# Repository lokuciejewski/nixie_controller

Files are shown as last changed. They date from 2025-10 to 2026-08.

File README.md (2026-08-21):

# Controller/clock for mini Nixie I2C modules

STM32-based controller board that uses 4 [nixie modules](https://github.com/lokuciejewski/nixie_module) to display the current time. The modules can be changed at any time the board is off and swapped if the nixie tube goes bad or the user wants to insert a different nixie tube.

V1 board with 4 modules

The board uses a STM32U031 microcontroller coupled with DS3231 RTC to achieve low power, reliable timekeeping.
For High Voltage for the nixie tubes, it uses a premade nixie PSU 160-180V (available on aliexpress). It uses a single cell CR2032 battery to keep the time when the module is not connected. For communication, it uses a serial interface over the USB-C port (which also serves as the power input). The board features 3 programmable buttons and two LEDs for signalling the system status.

V1 empty board
Note: V1 version of the board contains multiple test points and additional inputs which will be removed in the V2 version.

## Building

Prerequisites:

- Rust
- `cargo`

To build, simply run `cargo build --release`

## Flashing

The board is flashed using `probe-rs`, which can utilize a range of multiple programmers, for example an ST-Link.
Connect the programmer to the J3 and run `cargo run --release`.

## Operation

Currently, the time can only be set using the serial port and the `comm.py` script.

The serial protocol for talking to the board can be found [in the `serial` directory](./src/serial/)

## Planned features

V2 will have an option to wire 1 or 2 neon tubes between the hour and minute displays (since not all nixie tubes come with a comma).

It may also be equipped with the human presence sensor to only light up when it can detect a human.

A console interface is planned to utilize all features of the board (such as programming inputs, time, etc.)

The board has a second serial available on pins which may be used for wireless time access via e.g. an esp32.

V1 board with nixies off

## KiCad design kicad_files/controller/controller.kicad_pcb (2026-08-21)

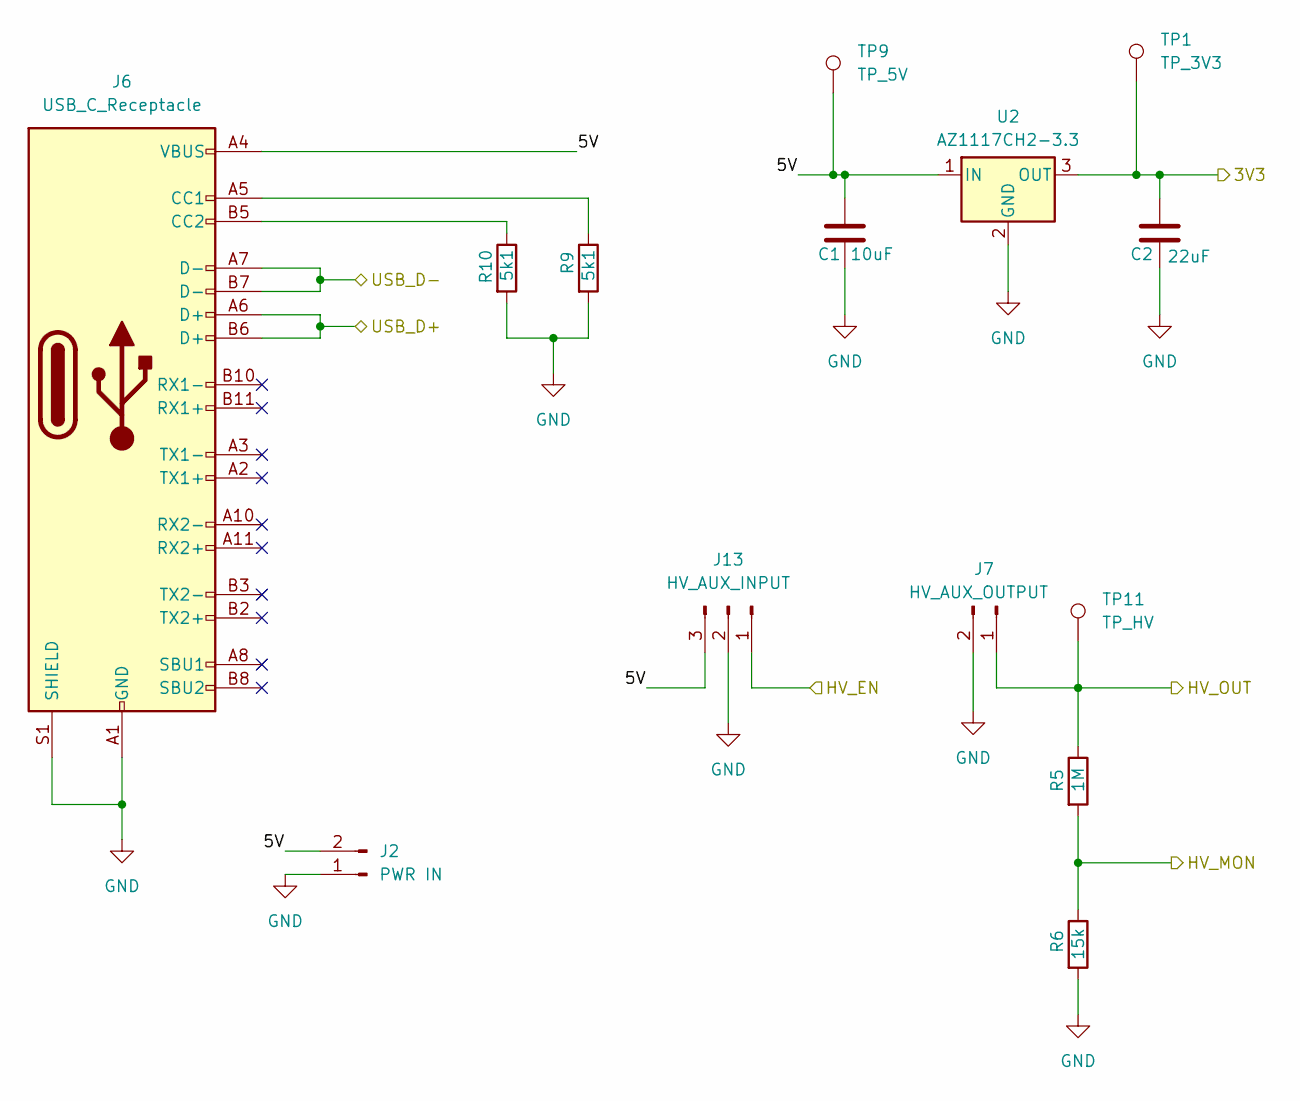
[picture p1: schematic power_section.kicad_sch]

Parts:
C1: 10uF; C_0603_1608Metric_Pad1.08x0.95mm_HandSolder
C2: 22uF; C_0603_1608Metric_Pad1.08x0.95mm_HandSolder
J2: PWR IN; PinHeader_1x02_P2.54mm_Vertical
J6: USB_C_Receptacle; USB_C_Receptacle_GCT_USB4085
J7: HV_AUX_OUTPUT; PinHeader_1x02_P2.54mm_Vertical
J13: HV_AUX_INPUT; PinHeader_1x03_P2.54mm_Vertical
R5: 1M; R_0805_2012Metric_Pad1.20x1.40mm_HandSolder
R6: 15k; R_0603_1608Metric_Pad0.98x0.95mm_HandSolder
R9, R10: 5k1; R_0603_1608Metric_Pad0.98x0.95mm_HandSolder
TP1: TP_3V3; TestPoint_Pad_D1.0mm
TP9: TP_5V; TestPoint_Pad_D1.0mm
TP11: TP_HV; TestPoint_Pad_D1.0mm
U2: AZ1117CH2-3.3; SOT-223-3_TabPin2

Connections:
/MCU/3V3: C2.1, TP1.1, U2.3 (OUT); also elsewhere on the board
/MCU/HV_EN: J13.1; also elsewhere on the board
/MCU/HV_MON: R5.2, R6.1; also elsewhere on the board
/MCU/USB_D+: J6.A6 (D+), J6.B6 (D+); also elsewhere on the board
/MCU/USB_D-: J6.A7 (D-), J6.B7 (D-); also elsewhere on the board
/Nixie Module Mounts/HV0: J7.1, R5.1, TP11.1; also elsewhere on the board
/Power Section/5V: C1.1, J2.2, J6.A4 (VBUS), J6.A9 (VBUS), J6.B4 (VBUS), J6.B9 (VBUS), J13.3, TP9.1, U2.1 (IN)
GND: C1.2, C2.2, J2.1, J6.A1 (GND), J6.A12 (GND), J6.B1 (GND), J6.B12 (GND), J6.S1 (SHIELD), J7.2, J13.2, R6.2, R9.2, R10.2, U2.2 (GND); also elsewhere on the board
unnamed: J6.A5 (CC1), R9.1
unnamed: J6.B5 (CC2), R10.1

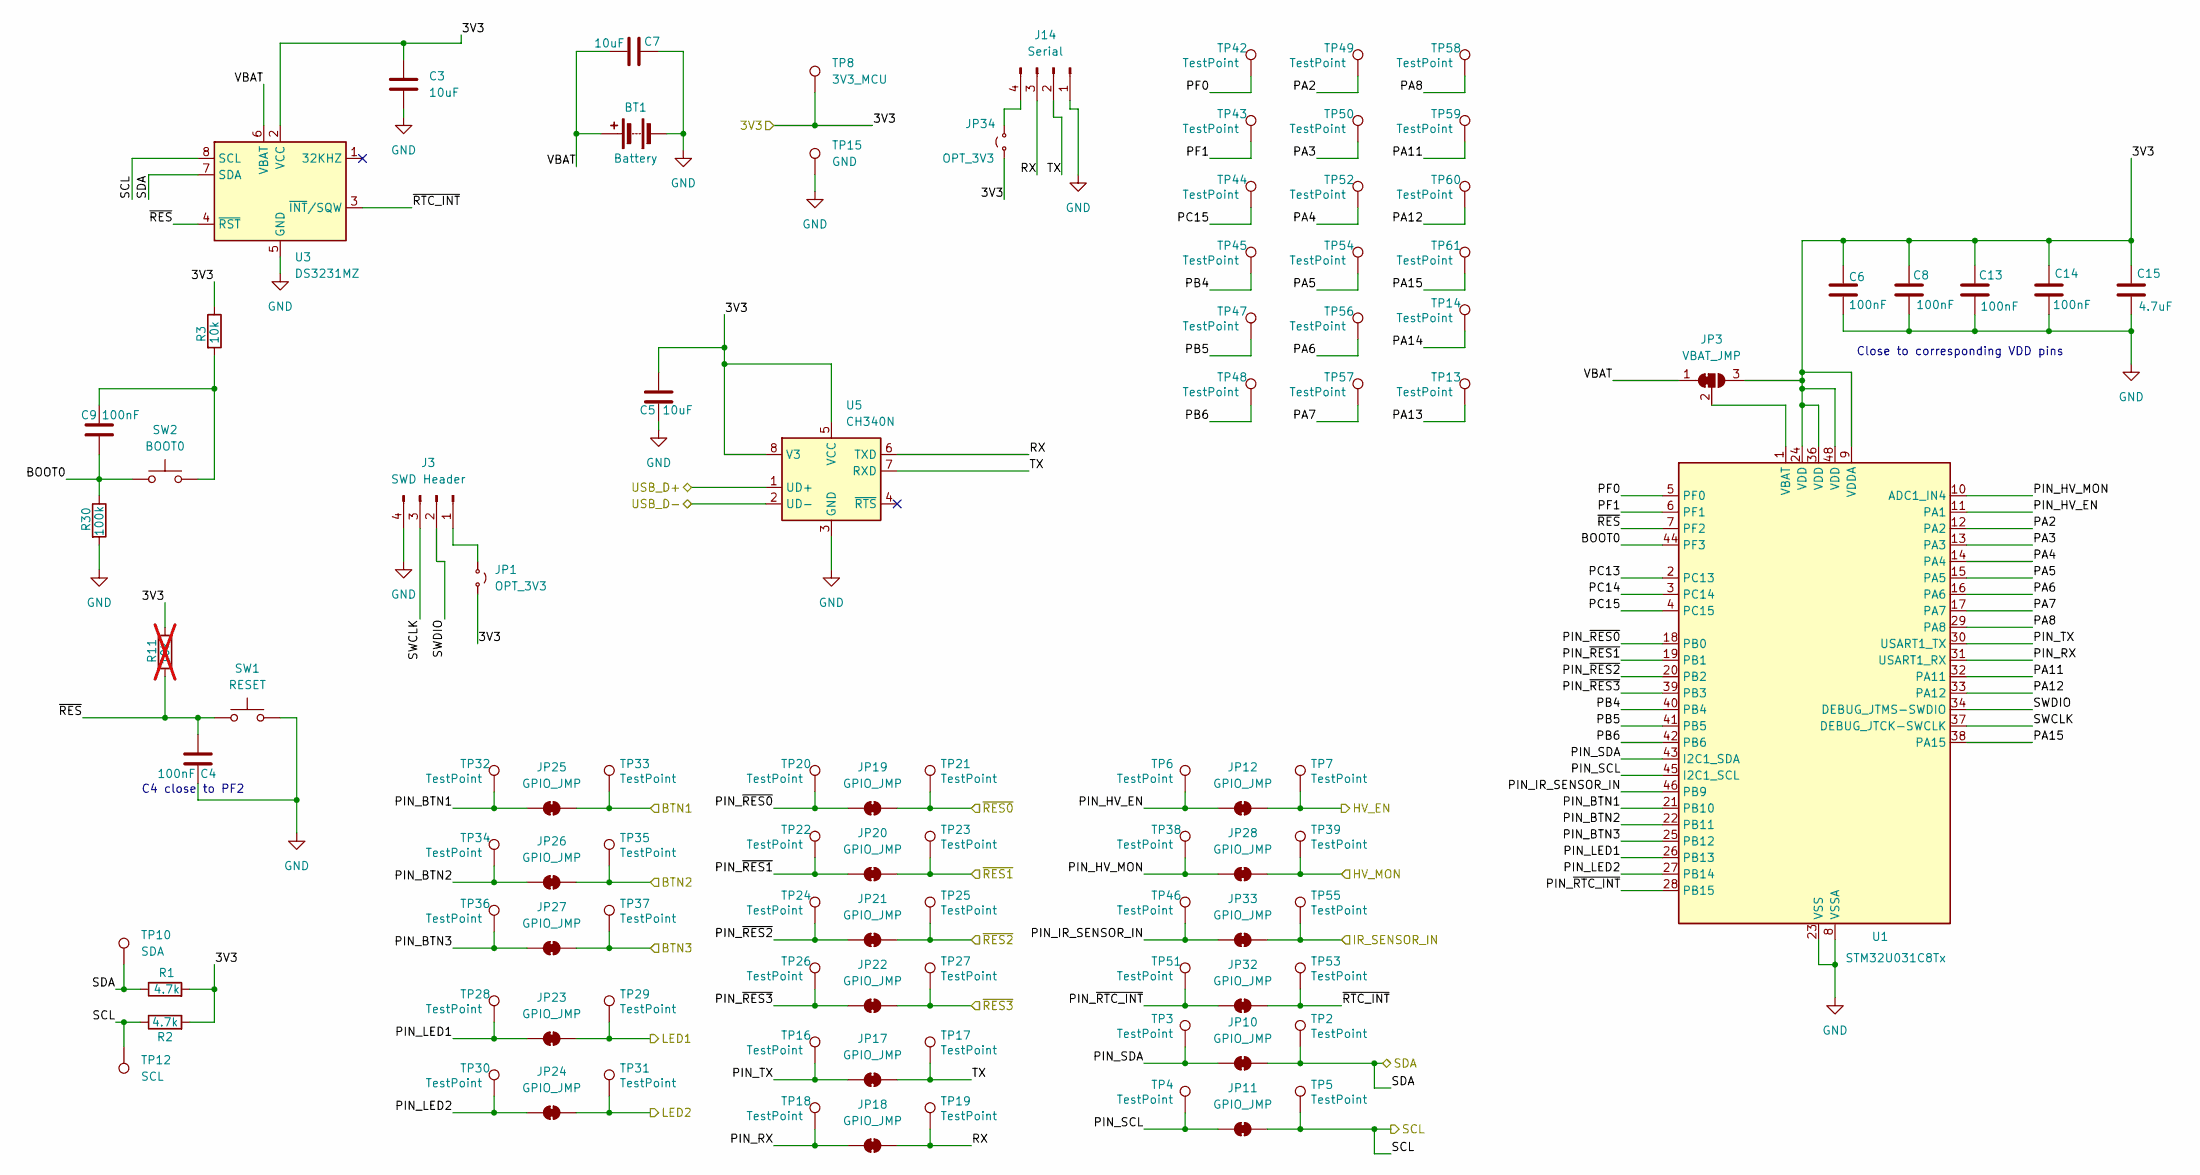
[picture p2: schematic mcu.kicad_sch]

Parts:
BT1: Battery; BatteryHolder_Keystone_1060_1x2032
C3, C5, C7: 10uF; C_0603_1608Metric_Pad1.08x0.95mm_HandSolder
C4, C6, C8, C9, C13, C14: 100nF; C_0603_1608Metric_Pad1.08x0.95mm_HandSolder
C15: 4.7uF; C_0603_1608Metric_Pad1.08x0.95mm_HandSolder
J3: SWD Header; PinHeader_1x04_P2.54mm_Vertical
J14: Serial; PinHeader_1x04_P2.54mm_Vertical
JP1, JP34: OPT_3V3; SolderJumper-2_P1.3mm_Open_RoundedPad1.0x1.5mm
JP3: VBAT_JMP; SolderJumper-3_P1.3mm_Bridged2Bar12_RoundedPad1.0x1.5mm_Num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
JP10, JP11, JP12, JP17, JP18, JP19, JP20, JP21, JP22, JP23, JP24, JP25, JP26, JP27, JP28, JP32, JP33: GPIO_JMP; SolderJumper-2_P1.3mm_Bridged2Bar_RoundedPad1.0x1.5mm
R1, R2: 4.7k; R_0603_1608Metric_Pad0.98x0.95mm_HandSolder
R3: 10k; R_0603_1608Metric_Pad0.98x0.95mm_HandSolder
R11: 10k; R_0603_1608Metric_Pad0.98x0.95mm_HandSolder; not fitted
R30: 100k; R_0603_1608Metric_Pad0.98x0.95mm_HandSolder
SW1: RESET; SW_SPST_TL3305A
SW2: BOOT0; SW_SPST_TL3305A
TP2, TP3, TP4, TP5, TP6, TP7, TP13, TP14, TP16, TP17, TP18, TP19, TP20, TP21, TP22, TP23, TP24, TP25, TP26, TP27, TP28, TP29, TP30, TP31, TP32, TP33, TP34, TP35, TP36, TP37, TP38, TP39, TP42, TP43, TP44, TP45, TP46, TP47, TP48, TP49, TP50, TP51, TP52, TP53, TP54, TP55, TP56, TP57, TP58, TP59, TP60, TP61: TestPoint; TestPoint_Pad_D1.0mm
TP8: 3V3_MCU; TestPoint_Pad_D1.0mm
TP10: SDA; TestPoint_Pad_D1.0mm
TP12: SCL; TestPoint_Pad_D1.0mm
TP15: GND; TestPoint_Pad_D1.0mm
U1: STM32U031C8Tx; LQFP-48_7x7mm_P0.5mm
U3: DS3231MZ; SOIC-8_3.9x4.9mm_P1.27mm
U5: CH340N; JEITA_SOIC-8_3.9x4.9mm_P1.27mm

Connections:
/IO Section/BTN_1: JP25.2 (B), TP33.1; also elsewhere on the board
/IO Section/BTN_2: JP26.2 (B), TP35.1; also elsewhere on the board
/IO Section/BTN_3: JP27.2 (B), TP37.1; also elsewhere on the board
/IO Section/IR_SENSOR_OUT: JP33.2 (B), TP55.1; also elsewhere on the board
/IO Section/LED_1: JP23.2 (B), TP29.1; also elsewhere on the board
/IO Section/LED_2: JP24.2 (B), TP31.1; also elsewhere on the board
/MCU/3V3: C3.1, C5.1, C6.1, C8.1, C13.1, C14.1, C15.1, JP1.2 (B), JP3.3 (B), JP34.1 (A), R1.2, R2.2, R3.1, R11.1, TP8.1, U1.9 (VDDA), U1.24 (VDD), U1.36 (VDD), U1.48 (VDD), U3.2 (VCC), U5.5 (VCC), U5.8 (V3); also elsewhere on the board
/MCU/BOOT0: C9.1, R30.1, SW2.1, U1.44 (PF3)
/MCU/HV_EN: JP12.2 (B), TP7.1; also elsewhere on the board
/MCU/HV_MON: JP28.2 (B), TP39.1; also elsewhere on the board
/MCU/PA2: TP49.1, U1.12 (PA2)
/MCU/PA3: TP50.1, U1.13 (PA3)
/MCU/PA4: TP52.1, U1.14 (PA4)
/MCU/PA5: TP54.1, U1.15 (PA5)
/MCU/PA6: TP56.1, U1.16 (PA6)
/MCU/PA7: TP57.1, U1.17 (PA7)
/MCU/PA8: TP58.1, U1.29 (PA8)
/MCU/PA11: TP59.1, U1.32 (PA11)
/MCU/PA12: TP60.1, U1.33 (PA12)
/MCU/PA13: TP13.1
/MCU/PA14: TP14.1
/MCU/PA15: TP61.1, U1.38 (PA15)
/MCU/PB4: TP45.1, U1.40 (PB4)
/MCU/PB5: TP47.1, U1.41 (PB5)
/MCU/PB6: TP48.1, U1.42 (PB6)
/MCU/PC13: U1.2 (PC13)
/MCU/PC14: U1.3 (PC14)
/MCU/PC15: TP44.1, U1.4 (PC15)
/MCU/PF0: TP42.1, U1.5 (PF0)
/MCU/PF1: TP43.1, U1.6 (PF1)
/MCU/PIN_BTN1: JP25.1 (A), TP32.1, U1.21 (PB10)
/MCU/PIN_BTN2: JP26.1 (A), TP34.1, U1.22 (PB11)
/MCU/PIN_BTN3: JP27.1 (A), TP36.1, U1.25 (PB12)
/MCU/PIN_HV_EN: JP12.1 (A), TP6.1, U1.11 (PA1)
/MCU/PIN_HV_MON: JP28.1 (A), TP38.1, U1.10 (ADC1_IN4)
/MCU/PIN_IR_SENSOR_IN: JP33.1 (A), TP46.1, U1.46 (PB9)
/MCU/PIN_LED1: JP23.1 (A), TP28.1, U1.26 (PB13)
/MCU/PIN_LED2: JP24.1 (A), TP30.1, U1.27 (PB14)
/MCU/PIN_RX: JP18.1 (A), TP18.1, U1.31 (USART1_RX)
/MCU/PIN_SCL: JP11.1 (A), TP4.1, U1.45 (I2C1_SCL)
/MCU/PIN_SDA: JP10.1 (A), TP3.1, U1.43 (I2C1_SDA)
/MCU/PIN_TX: JP17.1 (A), TP16.1, U1.30 (USART1_TX)
/MCU/PIN_~RES0: JP19.1 (A), TP20.1, U1.18 (PB0)
/MCU/PIN_~RES1: JP20.1 (A), TP22.1, U1.19 (PB1)
/MCU/PIN_~RES2: JP21.1 (A), TP24.1, U1.20 (PB2)
/MCU/PIN_~RES3: JP22.1 (A), TP26.1, U1.39 (PB3)
/MCU/PIN_~RTC_INT: JP32.1 (A), TP51.1, U1.28 (PB15)
/MCU/RX: J14.3, JP18.2 (B), TP19.1, U5.6 (TXD)
/MCU/SCL: JP11.2 (B), R2.1, TP5.1, TP12.1, U3.8 (SCL); also elsewhere on the board
/MCU/SDA: JP10.2 (B), R1.1, TP2.1, TP10.1, U3.7 (SDA); also elsewhere on the board
/MCU/SWCLK: J3.3, U1.37 (DEBUG_JTCK-SWCLK)
/MCU/SWDIO: J3.2, U1.34 (DEBUG_JTMS-SWDIO)
/MCU/TX: J14.2, JP17.2 (B), TP17.1, U5.7 (RXD)
/MCU/USB_D+: U5.1 (UD+); also elsewhere on the board
/MCU/USB_D-: U5.2 (UD-); also elsewhere on the board
/MCU/VBAT: BT1.1 (+), C7.2, JP3.1 (A), U3.6 (VBAT)
/MCU/~RES0: JP19.2 (B), TP21.1; also elsewhere on the board
/MCU/~RES1: JP20.2 (B), TP23.1; also elsewhere on the board
/MCU/~RES2: JP21.2 (B), TP25.1; also elsewhere on the board
/MCU/~RES3: JP22.2 (B), TP27.1; also elsewhere on the board
/MCU/~RES: C4.1, R11.2, SW1.1, U1.7 (PF2), U3.4 (~RST)
/MCU/~RTC_INT: JP32.2 (B), TP53.1, U3.3 (~INT/SQW)
GND: BT1.2 (-), C3.2, C4.2, C5.2, C6.2, C7.1, C8.2, C13.2, C14.2, C15.2, J3.4, J14.1, R30.2, SW1.2, TP15.1, U1.8 (VSSA), U1.23 (VSS), U3.5 (GND), U5.3 (GND); also elsewhere on the board
unnamed: C9.2, R3.2, SW2.2
unnamed: J3.1, JP1.1 (A)
unnamed: J14.4, JP34.2 (B)
unnamed: JP3.2 (C), U1.1 (VBAT)
unnamed: U1.35 (VSS), U1.47 (VSS)

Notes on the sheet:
Close to corresponding VDD pins
C4 close to PF2

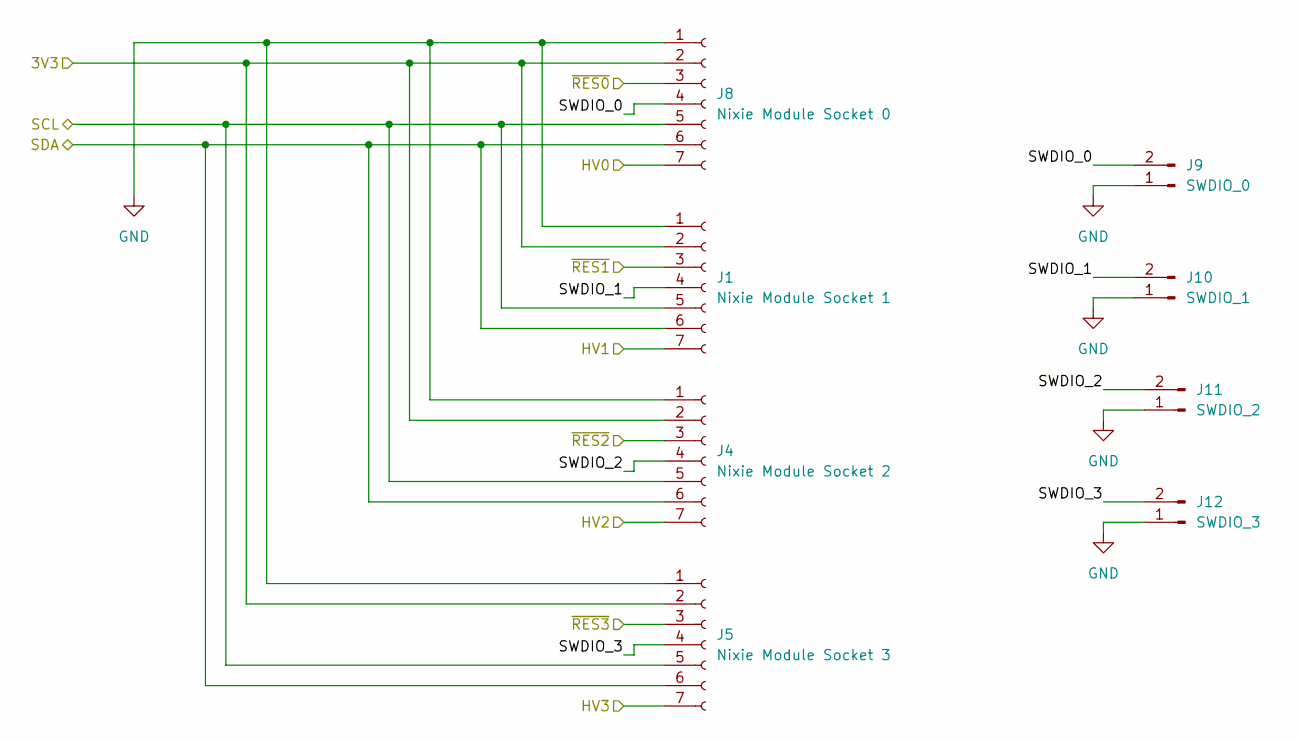
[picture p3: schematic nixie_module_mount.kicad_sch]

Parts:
J1: Nixie Module Socket 1; PinHeader_1x07_P2.54mm_Vertical
J4: Nixie Module Socket 2; PinHeader_1x07_P2.54mm_Vertical
J5: Nixie Module Socket 3; PinHeader_1x07_P2.54mm_Vertical
J8: Nixie Module Socket 0; PinHeader_1x07_P2.54mm_Vertical
J9: SWDIO_0; PinHeader_1x02_P2.54mm_Vertical
J10: SWDIO_1; PinHeader_1x02_P2.54mm_Vertical
J11: SWDIO_2; PinHeader_1x02_P2.54mm_Vertical
J12: SWDIO_3; PinHeader_1x02_P2.54mm_Vertical

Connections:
/MCU/3V3: J1.2, J4.2, J5.2, J8.2; also elsewhere on the board
/MCU/SCL: J1.5, J4.5, J5.5, J8.5; also elsewhere on the board
/MCU/SDA: J1.6, J4.6, J5.6, J8.6; also elsewhere on the board
/MCU/~RES0: J8.3; also elsewhere on the board
/MCU/~RES1: J1.3; also elsewhere on the board
/MCU/~RES2: J4.3; also elsewhere on the board
/MCU/~RES3: J5.3; also elsewhere on the board
/Nixie Module Mounts/HV0: J1.7, J4.7, J5.7, J8.7; also elsewhere on the board
/Nixie Module Mounts/SWDIO_0: J8.4, J9.2
/Nixie Module Mounts/SWDIO_1: J1.4, J10.2
/Nixie Module Mounts/SWDIO_2: J4.4, J11.2
/Nixie Module Mounts/SWDIO_3: J5.4, J12.2
GND: J1.1, J4.1, J5.1, J8.1, J9.1, J10.1, J11.1, J12.1; also elsewhere on the board

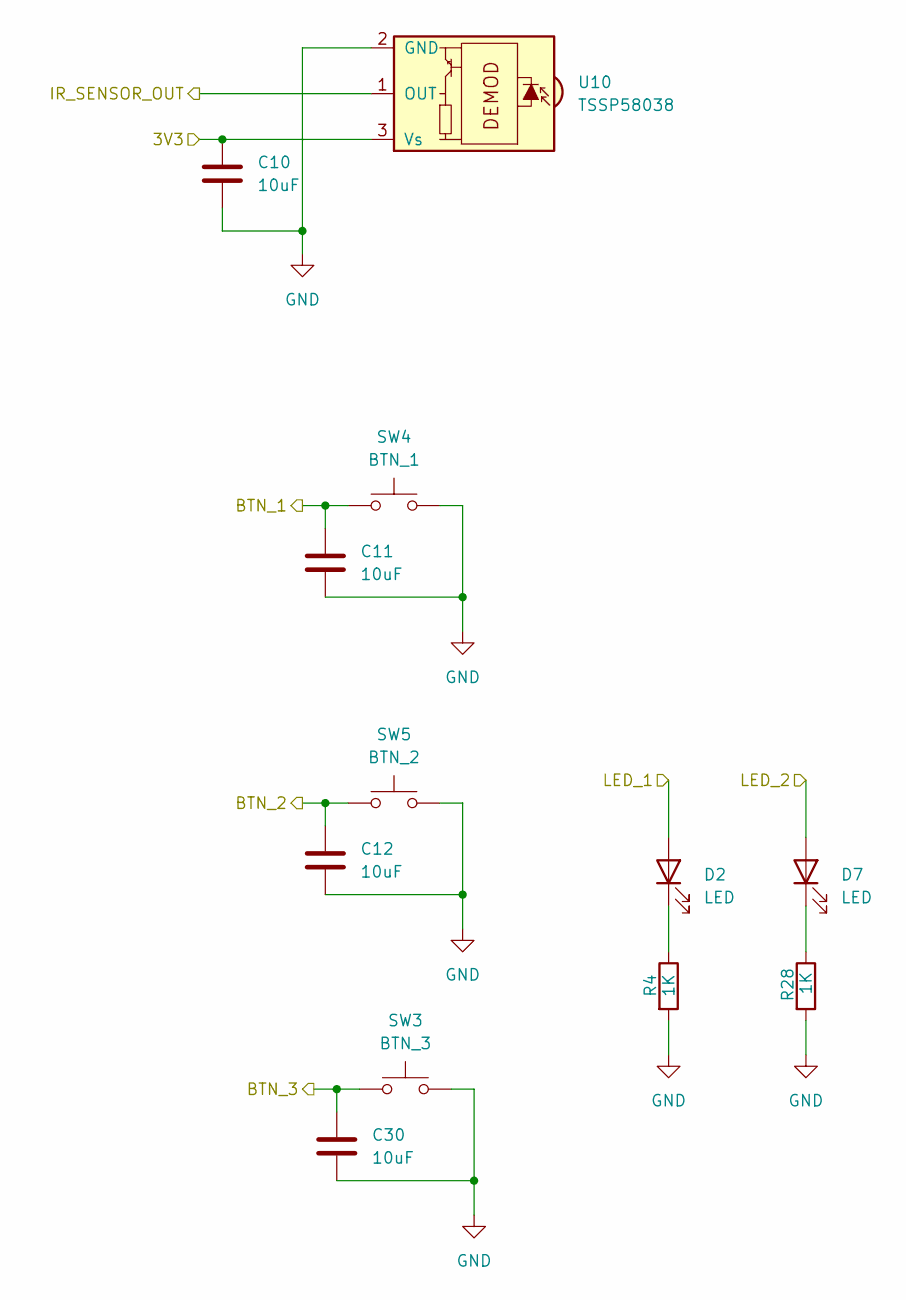
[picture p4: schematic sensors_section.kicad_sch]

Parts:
C10, C11, C12, C30: 10uF; C_0603_1608Metric_Pad1.08x0.95mm_HandSolder
D2, D7: LED; LED_0603_1608Metric_Pad1.05x0.95mm_HandSolder
R4, R28: 1K; R_0603_1608Metric_Pad0.98x0.95mm_HandSolder
SW3: BTN_3; SW_Tactile_SPST_Angled_PTS645Vx39-2LFS
SW4: BTN_1; SW_Tactile_SPST_Angled_PTS645Vx39-2LFS
SW5: BTN_2; SW_Tactile_SPST_Angled_PTS645Vx39-2LFS
U10: TSSP58038; Vishay_MINICAST-3Pin

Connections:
/IO Section/BTN_1: C11.1, SW4.1; also elsewhere on the board
/IO Section/BTN_2: C12.1, SW5.1; also elsewhere on the board
/IO Section/BTN_3: C30.1, SW3.1; also elsewhere on the board
/IO Section/IR_SENSOR_OUT: U10.1 (OUT); also elsewhere on the board
/IO Section/LED_1: D2.2 (A); also elsewhere on the board
/IO Section/LED_2: D7.2 (A); also elsewhere on the board
/MCU/3V3: C10.1, U10.3 (Vs); also elsewhere on the board
GND: C10.2, C11.2, C12.2, C30.2, R4.2, R28.2, SW3.2, SW4.2, SW5.2, U10.2 (GND); also elsewhere on the board
unnamed: D2.1 (K), R4.1
unnamed: D7.1 (K), R28.1

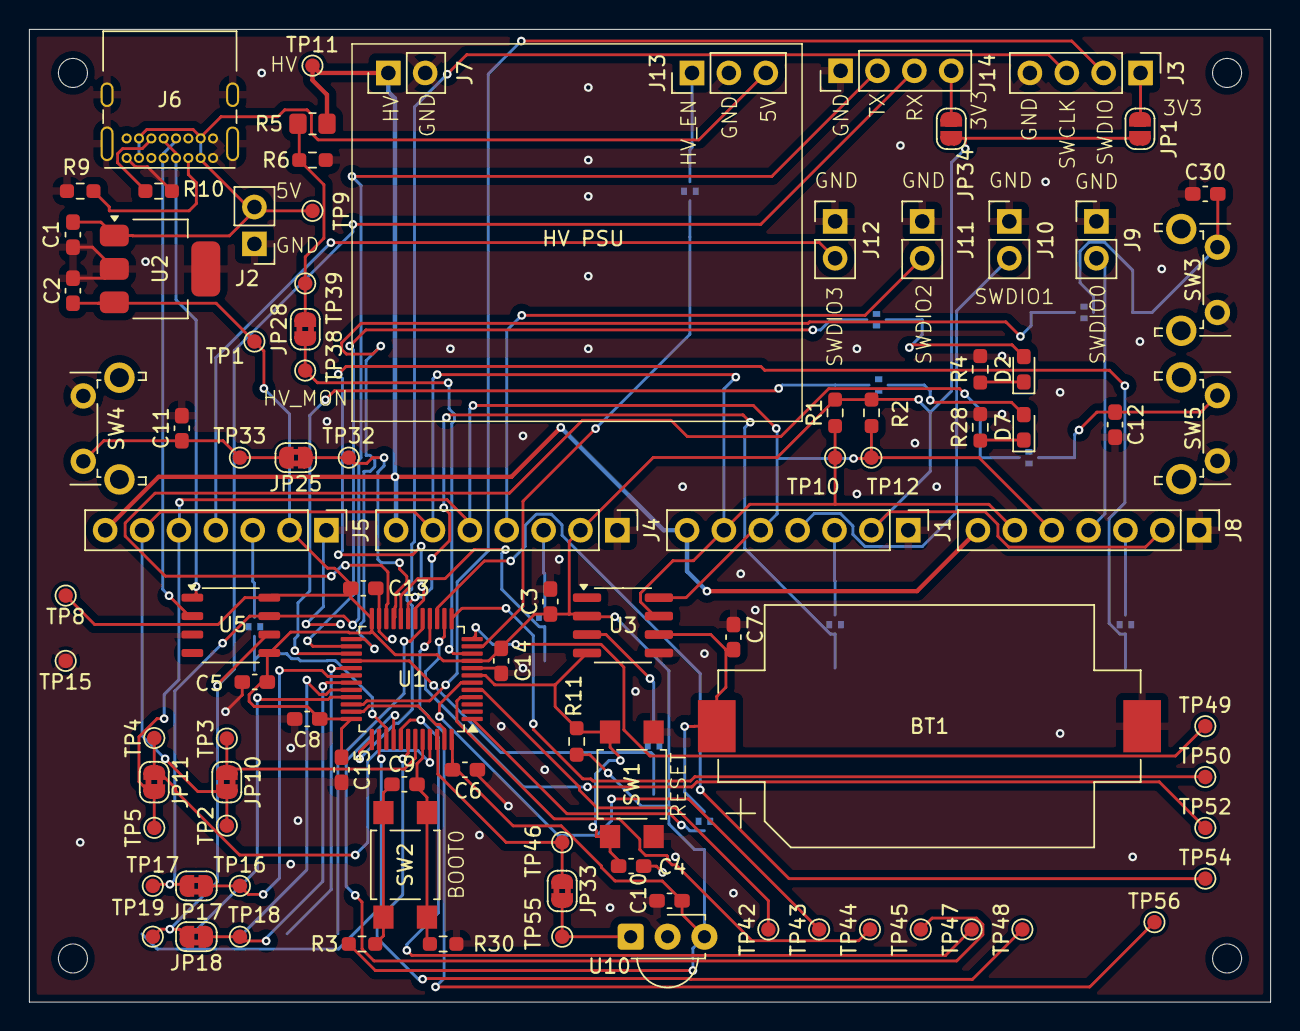
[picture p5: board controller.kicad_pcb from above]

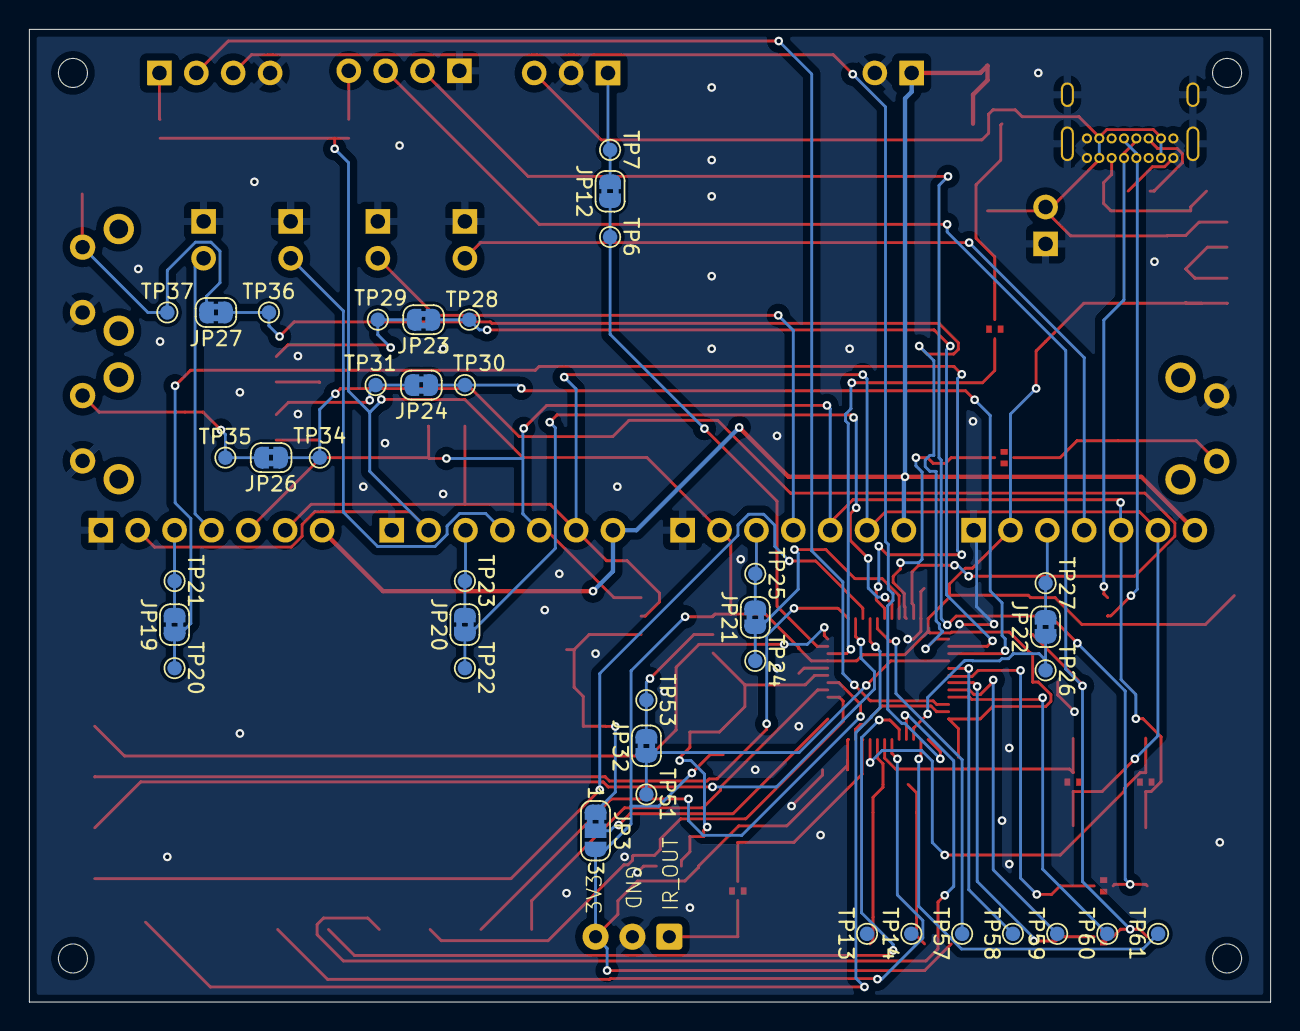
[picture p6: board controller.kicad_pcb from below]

Board: 2 copper layers, 85.5 x 67.0 mm, 133 parts (38 on the bottom side), 74 nets.

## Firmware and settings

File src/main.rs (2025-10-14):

#![no_std]
#![no_main]

mod board_config;
mod buttons;
mod ir_sensor;
mod leds;
mod nixie_controller;
mod rtc;
mod serial;

use chrono::{NaiveDateTime, Timelike};
use embassy_stm32::peripherals::USART1;
use embassy_sync::blocking_mutex::raw::{CriticalSectionRawMutex, NoopRawMutex};
use embassy_sync::mutex::Mutex;
use embassy_sync::signal::Signal;
use embassy_sync::watch::Watch;
use static_cell::StaticCell;

use crate::board_config::*;
use crate::buttons::button_task;
use crate::ir_sensor::ir_sensor_task;
use crate::leds::{led_task, SystemState};
use crate::nixie_controller::nixie_controller_task;
use crate::rtc::rtc_task;
use crate::serial::protocol::ProgramMode;
use crate::serial::serial::serial_task;
use cortex_m_rt::{exception, ExceptionFrame};
use defmt::*;
use defmt_rtt as _;
use embassy_executor::Spawner;
use embassy_stm32::{bind_interrupts, i2c::I2c, peripherals::I2C1};
use embassy_time::{Duration, Ticker};
use panic_probe as _;

use defmt::panic;

type I2cBus =
    Mutex<NoopRawMutex, I2c<'static, embassy_stm32::mode::Async, embassy_stm32::i2c::Master>>;

bind_interrupts!(struct Irqs {
    I2C1 => embassy_stm32::i2c::EventInterruptHandler<I2C1>, embassy_stm32::i2c::ErrorInterruptHandler<I2C1>;
    USART1 => embassy_stm32::usart::InterruptHandler<USART1>;
});

type TimeWatch = Watch<CriticalSectionRawMutex, NaiveDateTime, 3>;
type TimeSignal = Signal<CriticalSectionRawMutex, NaiveDateTime>;
type StateWatch = Watch<CriticalSectionRawMutex, SystemState, 3>;

static TIME_WATCH: TimeWatch = Watch::new();
static TIME_SIGNAL_SER_RTC: TimeSignal = Signal::new();
static DISPLAY_SIGNAL: Signal<CriticalSectionRawMutex, (u16, bool)> = Signal::new();

static CURRENT_STATE: StateWatch = Watch::new();

static MOVEMENT_DETECTED: Signal<CriticalSectionRawMutex, bool> = Signal::new();

static BUTTON_1_PRESSED: Signal<CriticalSectionRawMutex, bool> = Signal::new();
static BUTTON_2_PRESSED: Signal<CriticalSectionRawMutex, bool> = Signal::new();
static BUTTON_3_PRESSED: Signal<CriticalSectionRawMutex, bool> = Signal::new();

pub fn set_system_state(state: SystemState) {
    let sender = CURRENT_STATE.sender();
    sender.send(state);
    info!("System state now set to {:?}", state);
}

#[embassy_executor::main]
async fn main(spawner: Spawner) -> ! {
    let p = embassy_stm32::init(Default::default());
    spawner
        .spawn(ir_sensor_task(ir_sensor_resources!(p), &MOVEMENT_DETECTED))
        .unwrap();
    spawner
        .spawn(button_task(
            button_resources!(p),
            &BUTTON_1_PRESSED,
            &BUTTON_2_PRESSED,
            &BUTTON_3_PRESSED,
        ))
        .unwrap();
    spawner
        .spawn(led_task(led_resources!(p), &CURRENT_STATE))
        .unwrap();

    set_system_state(leds::SystemState::Init);

    let i = i2c_resources!(p);
    let mut i2c_config = embassy_stm32::i2c::Config::default();
    i2c_config.timeout = Duration::from_millis(50);
    let i2c = I2c::new(
        i.i2c_instance,
        i.scl,
        i.sda,
        Irqs,
        p.DMA1_CH1,
        p.DMA1_CH2,
        i2c_config,
    );
    static I2C_BUS: StaticCell<I2cBus> = StaticCell::new();
    let i2c_bus = I2C_BUS.init(Mutex::new(i2c));

    spawner
        .spawn(serial_task(
            uart_resources!(p),
            &TIME_WATCH,
            &TIME_SIGNAL_SER_RTC,
        ))
        .unwrap();
    spawner
        .spawn(rtc_task(
            rtc_resources!(p),
            i2c_bus,
            &TIME_WATCH,
            &TIME_SIGNAL_SER_RTC,
        ))
        .unwrap();
    spawner
        .spawn(nixie_controller_task(
            module_resources!(p),
            hv_resources!(p),
            i2c_bus,
            &DISPLAY_SIGNAL,
        ))
        .unwrap();

    info!("Main program start");
    set_system_state(SystemState::Normal(ProgramMode::Clock));

    let mut time_changed = TIME_WATCH.receiver().unwrap();
    let mut state_recv = CURRENT_STATE.receiver().unwrap();

    let mut current_state = state_recv.get().await;
    let mut loop_ticker = Ticker::every(Duration::from_millis(500));

    loop {
        if let Some(new_state) = state_recv.try_changed() {
            current_state = new_state;
        }

        match current_state {
            SystemState::None => panic!("SystemState is set to None"),
            SystemState::Init => panic!("SystemState is set to Init"),
            SystemState::Normal(program_mode) => match program_mode {
                ProgramMode::Clock => {
                    let t = time_changed.changed().await;
                    let int = (t.hour() as u16) * 100 + (t.minute() as u16);
                    DISPLAY_SIGNAL.signal((int, t.second() % 2 == 0));
                }
                ProgramMode::ExternalControl => {}
                ProgramMode::FirmwareUpdate => {}
            },
            SystemState::Error => {}
        }

        loop_ticker.next().await;
    }
}

#[exception]
unsafe fn HardFault(_frame: &ExceptionFrame) -> ! {
    error!("HardFault!");
    set_system_state(SystemState::Error);
    loop {}
}

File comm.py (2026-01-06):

import serial
import time
import datetime


def get_datetime(ser: serial.Serial) -> int:
    command = [0x69, 0x1, 0x0, 0x1, 0, 0, 0, 0, 0, 0, 0, 0, 0, 0, 0, 0]
    ser.write(command)
    resp = ser.read(16)
    resp = [int(byte) for byte in resp]
    print(resp)
    print(resp[4:6])
    year = int.from_bytes(resp[4:6], byteorder="little")
    month = resp[6]
    day = resp[7]
    hour = resp[8]
    minute = resp[9]
    second = resp[10]
    return time.mktime((year, month, day, hour, minute, second, 0, 0, 0))


def set_datetime(ser: serial.Serial, datetime_struct):
    command = [
        0x69,
        0x1,
        0x0,
        0x0,
        datetime_struct.year & 0xFF,
        (datetime_struct.year >> 8) & 0xFF,
        datetime_struct.month,
        datetime_struct.day,
        datetime_struct.hour,
        datetime_struct.minute,
        datetime_struct.second,
        0,
        0,
        0,
        0,
        0,
    ]
    ser.write(command)


def main():
    with serial.Serial("/dev/ttyUSB0", 115200) as ser:
        current_time = get_datetime(ser)
        print(time.localtime(current_time))
        time.sleep(0.5)
        set_datetime(ser, datetime.datetime.now())
        time.sleep(0.5)
        current_time = get_datetime(ser)
        print(time.localtime(current_time))


if __name__ == "__main__":
    main()

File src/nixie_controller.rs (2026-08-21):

use core::{fmt::Debug, marker::PhantomData};

use defmt::{debug, error, info, Format};
use embassy_embedded_hal::shared_bus::asynch::i2c::I2cDevice;
use embassy_stm32::gpio::{Level, Output, Speed};
use embassy_sync::{blocking_mutex::raw::CriticalSectionRawMutex, signal::Signal};
use embassy_time::{Duration, Ticker, Timer};
use embedded_hal_async::i2c::I2c;
use heapless::index_map::FnvIndexMap;

use crate::{
    board_config::{HVResources, ModuleResources},
    I2cBus,
};

type DisplaySignal = Signal<CriticalSectionRawMutex, (u16, bool)>;

// Address which newly programmed modules have
const DEFAULT_MODULE_ADDRESS: u8 = 0x20;
// Address to start assigning new modules to
const FIRST_MODULE_ADDRESS: u8 = 0x40;
// Highest possible module address
const LAST_MODULE_ADDRESS: u8 = 0x46;
// Number of digits
const N_OF_DIGITS: usize = 4;

#[embassy_executor::task]
pub async fn nixie_controller_task(
    module_resources: ModuleResources,
    hv_resources: HVResources,
    i2c_bus: &'static I2cBus,
    display_signal: &'static DisplaySignal,
) -> ! {
    let reset_pins = [
        Output::new(module_resources.reset_0, Level::Low, Speed::High),
        Output::new(module_resources.reset_1, Level::Low, Speed::High),
        Output::new(module_resources.reset_2, Level::Low, Speed::High),
        Output::new(module_resources.reset_3, Level::Low, Speed::High),
    ];
    let hv_enable_pin = Output::new(
        hv_resources.hv_en,
        Level::High,
        embassy_stm32::gpio::Speed::VeryHigh,
    );
    let i2c_dev = I2cDevice::new(i2c_bus);
    let mut nixie_controller: NixieController<'_, _, N_OF_DIGITS> = NixieController::new(
        i2c_dev,
        hv_enable_pin,
        reset_pins,
        RefreshPolicy::EveryXMinutes(1),
    );

    while nixie_controller.get_max_number() == 0 {
        match nixie_controller.init_modules().await {
            Ok(_) => (),
            Err(e) => error!("{}", e),
        }
        Timer::after_millis(500).await;
    }
    info!("Max number: {}", nixie_controller.get_max_number());
    match nixie_controller.set_brightness(60).await {
        Ok(_) => {}
        Err(e) => {
            error!("Failed to set brightness: {:?}", e);
        }
    }
    let mut last_refresh = 0;
    loop {
        // The signal should be set every second
        let (num, comma) = display_signal.wait().await;
        match nixie_controller.refresh_policy {
            RefreshPolicy::EveryXMinutes(x) => {
                if num - last_refresh >= x.into() {
                    match nixie_controller.refresh_all(5).await {
                        Ok(_) => {
                            last_refresh = num;
                        }
                        Err(e) => error!("Module refresh failed : {:?}", e),
                    }
                }
            }
            RefreshPolicy::EveryXHours(x) => {
                if (num / 100) - last_refresh >= x.into() {
                    match nixie_controller.refresh_all(5).await {
                        Ok(_) => {
                            last_refresh = num;
                        }
                        Err(e) => error!("Module refresh failed : {:?}", e),
                    }
                }
            }
            RefreshPolicy::At(hour, minute) => {
                if (num / 100) == hour.into() && (num % 100) == minute.into() {
                    match nixie_controller.refresh_all(5).await {
                        Ok(_) => {
                            last_refresh = num;
                        }
                        Err(e) => error!("Module refresh failed : {:?}", e),
                    }
                }
            }
        }
        match nixie_controller.display_integer(num as usize).await {
            Ok(_) => {}
            Err(e) => error!("Cannot display integer {} : {:?}", num, e),
        }
        match nixie_controller.set_comma(1, comma).await {
            Ok(_) => {}
            Err(_) => error!("Cannot set comma on {} to {}", 1, comma),
        }
    }
}

pub enum NixieControllerError<I2C>
where
    I2C: I2c,
{
    CommunicationError(I2C::Error),
    InvalidParameter,
    InvalidPosition,
    ModuleNotFound,
    TooManyDigits,
    InternalError,
}

impl<I2C> Debug for NixieControllerError<I2C>
where
    I2C: I2c,
{
    fn fmt(&self, f: &mut core::fmt::Formatter<'_>) -> core::fmt::Result {
        match self {
            Self::CommunicationError(arg0) => {
                f.debug_tuple("CommunicationError").field(arg0).finish()
            }
            Self::InvalidParameter => write!(f, "InvalidParameter"),
            Self::InvalidPosition => write!(f, "InvalidPosition"),
            Self::TooManyDigits => write!(f, "TooManyDigits"),
            Self::InternalError => write!(f, "InternalError"),
            Self::ModuleNotFound => write!(f, "ModuleNotFound"),
        }
    }
}

impl<I2C> Format for NixieControllerError<I2C>
where
    I2C: I2c,
{
    fn format(&self, fmt: defmt::Formatter) {
        match self {
            Self::CommunicationError(_) => {
                defmt::write!(fmt, "CommunicationError")
            }
            Self::InvalidParameter => defmt::write!(fmt, "InvalidParameter"),
            Self::InvalidPosition => defmt::write!(fmt, "InvalidPosition"),
            Self::TooManyDigits => defmt::write!(fmt, "TooManyDigits"),
            Self::InternalError => defmt::write!(fmt, "InternalError"),
            Self::ModuleNotFound => defmt::write!(fmt, "ModuleNotFound"),
        }
    }
}

#[allow(unused)]
pub enum RefreshPolicy {
    EveryXMinutes(u8),
    EveryXHours(u8),
    /// Hour, Minute
    At(u8, u8),
}

pub struct NixieController<'nc, I2C, const N: usize>
where
    I2C: I2c,
{
    pin_positions: [Output<'nc>; N],
    nixie_modules: FnvIndexMap<u8, NixieModule<I2C>, N>,
    smallest_unavailable_number: usize,
    available_digits: usize,
    hv_enable: Output<'nc>,
    refresh_policy: RefreshPolicy,
    i2c: I2C,
}
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

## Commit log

2025-04-09 added IR motion sensor
2025-06-26 changed target to STM32U031F8Px
2025-08-14 added board_config for evalboard/sample_1
2025-08-15 lowered i2c timeout to speed up the device discovery
2025-08-20 more sample 1 changes
2025-08-25 restructured repo, minor fixes
    [board_config.rs, main.rs, nixie_controller.rs]
2025-08-28 fixed red led staying on in Normal state
2025-10-14 fixed bugs in python script, fixed some serialization bugs, added separate commands module
    [comm.py, serial.rs]
2025-10-14 added initial state switching architecture
2026-08-21 added kicad files
    [controller.kicad_pcb, controller.kicad_sch, mcu.kicad_sch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]
